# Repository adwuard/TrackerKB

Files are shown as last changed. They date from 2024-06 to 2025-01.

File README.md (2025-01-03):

### Fully Assembled units and parts are available here: 
Small batch custom build. Limited quantity now available and ready to ship!  
[Ed's Lab Shop](https://edslab.myshopify.com/)   
# Table of Contents
- [Table of Contents](#table-of-contents)
- [Overview](#overview)
- [Features](#features)
- [Hardware Guide](#hardware-guide)
    - [System Diagram](#system-diagram)
  - [Electronics Build Guide](#electronics-build-guide)
    - [Soldering](#soldering)
    - [Tips on Soldering Teensy 4.1](#tips-on-soldering-teensy-41)
  - [PCB Testing](#pcb-testing)
- [Three Versions of Enclosure are Available](#three-versions-of-enclosure-are-available)
    - [Option 1: CNC Machined Enclosure](#option-1-cnc-machined-enclosure)
    - [Option 2: Sandwiching Acrylic Enclosure](#option-2-sandwiching-acrylic-enclosure)
    - [Option 3: 3D Printed Enclosure](#option-3-3d-printed-enclosure)
- [Software Guide](#software-guide)
  - [1. Tracker Headless Firmware (Teensy 4.1)](#1-tracker-headless-firmware-teensy-41)
  - [2. Keyboard Firmware (RP2040 MCU)](#2-keyboard-firmware-rp2040-mcu)
    - [Keyboard Firmware Highlights](#keyboard-firmware-highlights)
    - [Pre-built keyboard firmware can be found here --\>  Keyboard Firmware](#pre-built-keyboard-firmware-can-be-found-here-----keyboard-firmware)
    - [Steps for Flashing Keyboard Firmware:](#steps-for-flashing-keyboard-firmware)

# Overview
This is a slightly over-engineered tracker keyboard that integrates both Teensy4.1 and a keyboard.

<div style="display: flex; flex-direction: row; margin-top: 20px;">
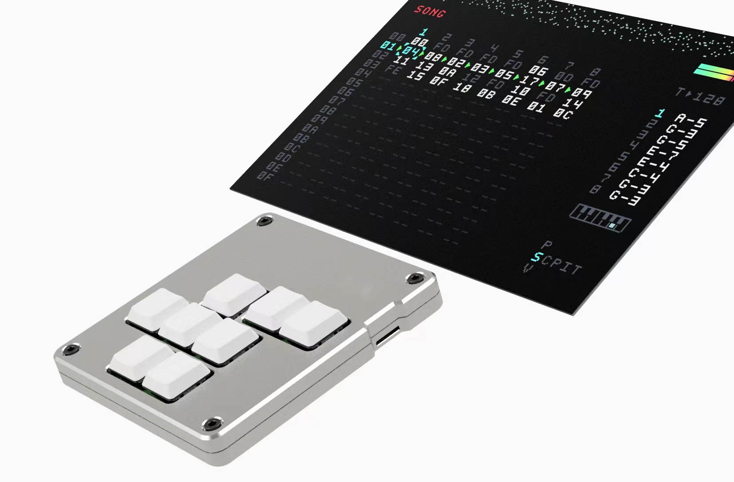
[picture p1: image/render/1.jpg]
  
</div>

<div style="display: flex; flex-direction: row; margin-top: 50px;">
  
</div>

# Features
- Built-in USB HUB connected to both Teensy 4.1 and Keyboard
- Keyboard is implemented with RP2040 microcontroller
- Same swappable mechanical keyboard as the original
- High-quality CNC machined case, providing the same handling experience as the original
- Robust connection with USB-C screw lock cable
  
# Hardware Guide
### System Diagram 
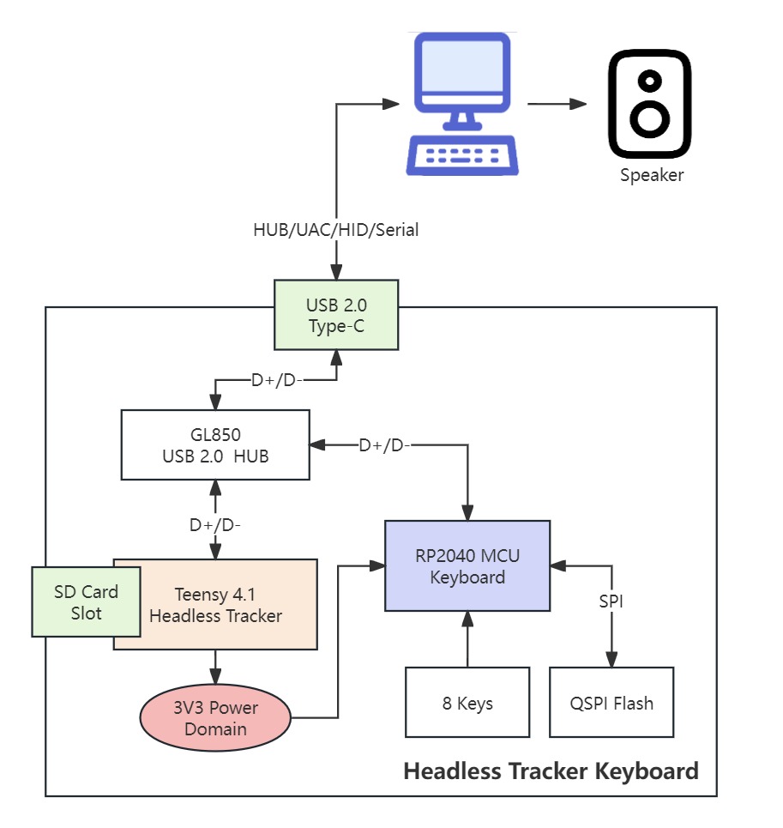
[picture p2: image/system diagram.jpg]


## Electronics Build Guide
Layer View          |  PCB (Front) |  PCB (Back)
:-------------------------:|:-------------------------:|:-------------------------:
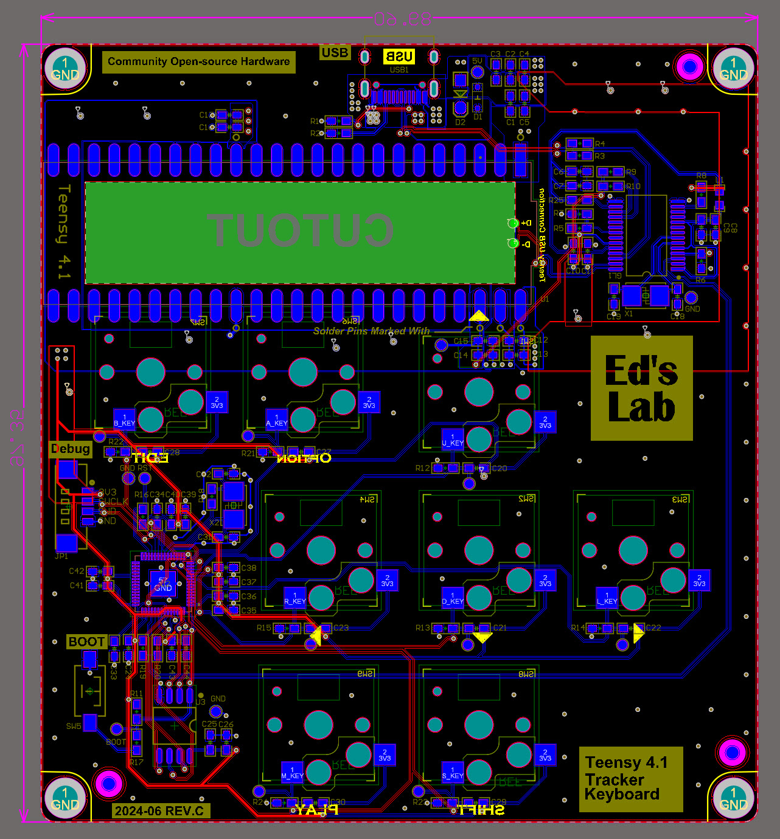
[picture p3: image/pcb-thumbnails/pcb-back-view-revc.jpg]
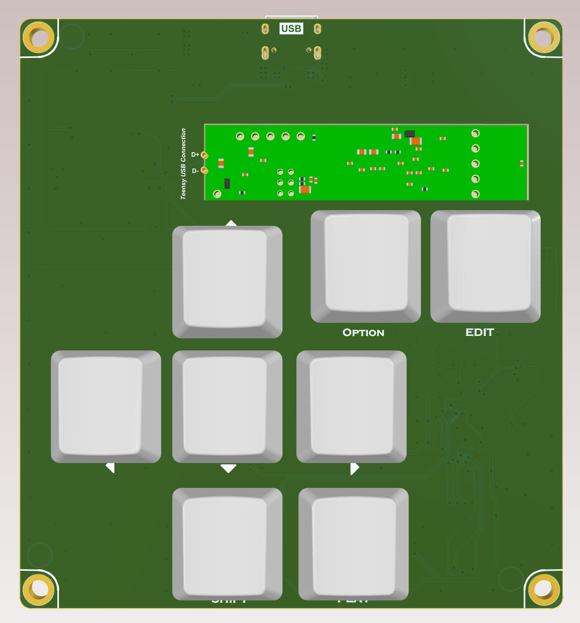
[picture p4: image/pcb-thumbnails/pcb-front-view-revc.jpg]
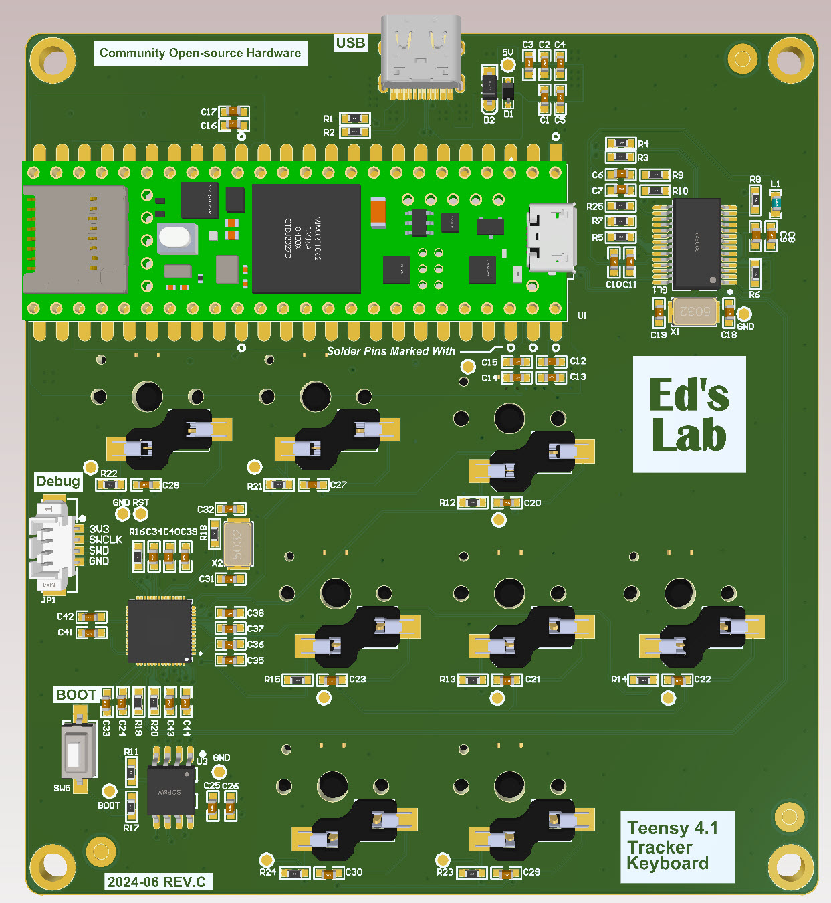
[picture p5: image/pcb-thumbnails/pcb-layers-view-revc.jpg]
 |  | 

PCB manufacture requirements: 
- Layers: `2-Layers`
- Board thickness: `1.6mm`
- Board dimensions: 90mm x 97.35mm 

All the components are 0603 footprints. The pads are designed with larger pads, making them great for hand-soldering. The most complex component in this project is the RP2040, which is in a QFN package, so hot-air reflow is required. An alternative approach is to make a custom PCB stencil, which would make the process much easier.

### Soldering
The stencil and reflow oven approach is demonstrated below and recommended. 
PCB | Stencil and Solder Paste | Pick and Place | Reflow Oven
:-:|:-:|:-:|:-:
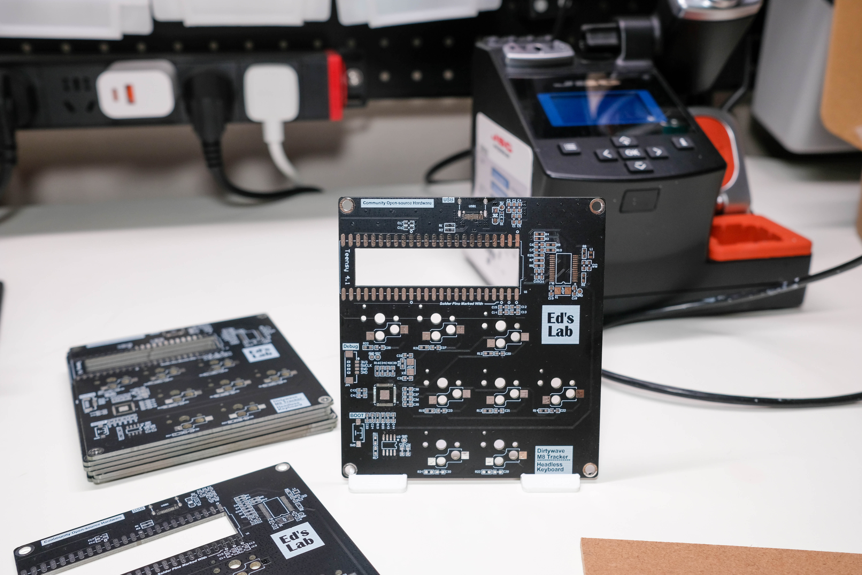
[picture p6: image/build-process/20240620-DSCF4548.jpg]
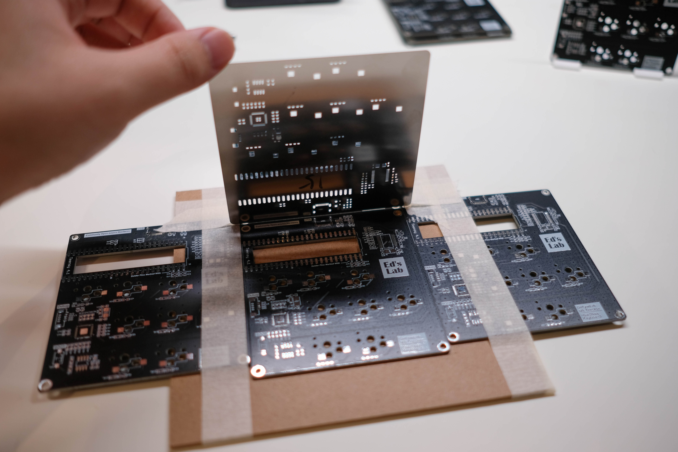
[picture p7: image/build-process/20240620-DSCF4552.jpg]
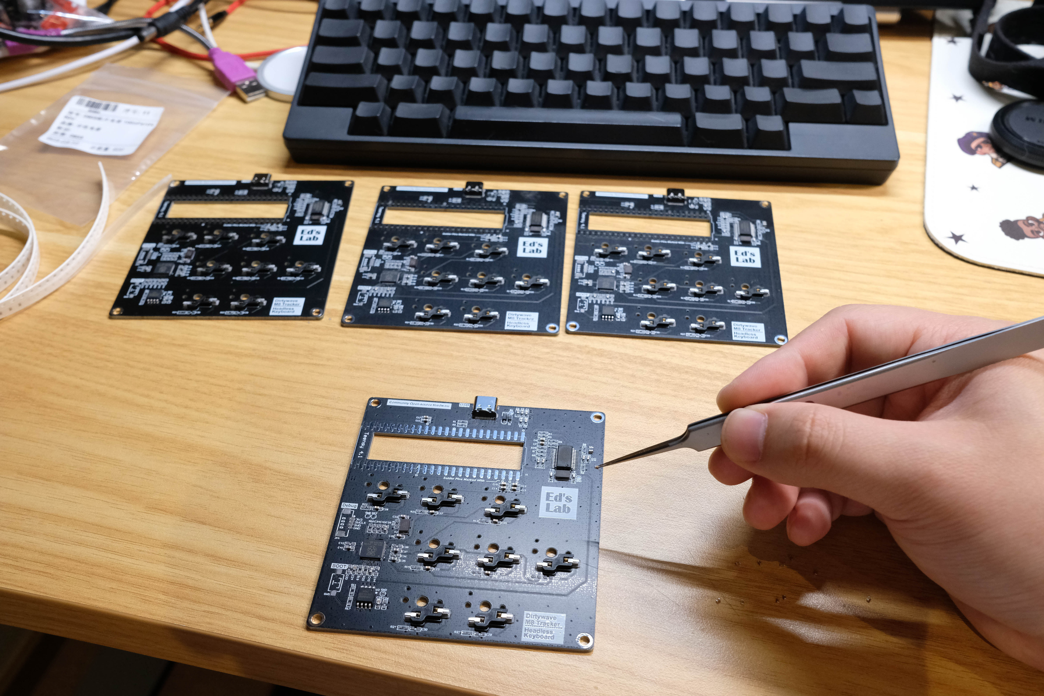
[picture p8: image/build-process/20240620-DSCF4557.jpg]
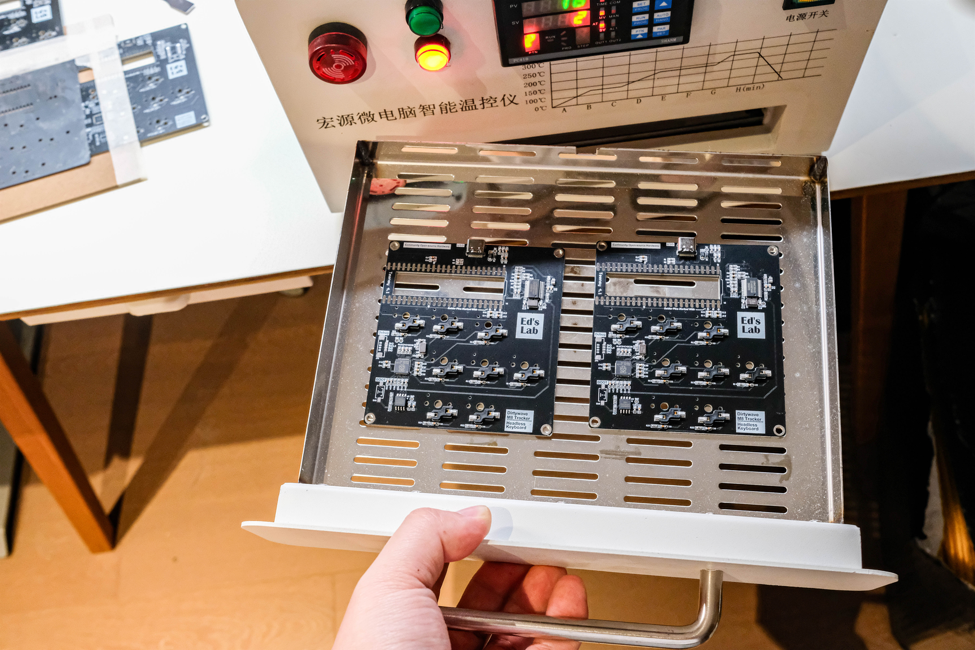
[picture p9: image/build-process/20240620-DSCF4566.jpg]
 | |  | 

### Tips on Soldering Teensy 4.1 
- Solder the pins that are marked with circles. Only 6 pins are required for soldering. This is enough to hold the board while still being easy to de-solder and repurpose if needed. To solder, add some solder flux onto the pads. Solder one pin first and ensure it's aligned properly. Place the soldering iron on the Teensy through-hole pad, and add a generous amount of solder. Hold the iron longer, around 8-15 seconds, and let the solder sink into the pad below. Then use multi-meter to test continuity between teensy pad and the pad directly below.
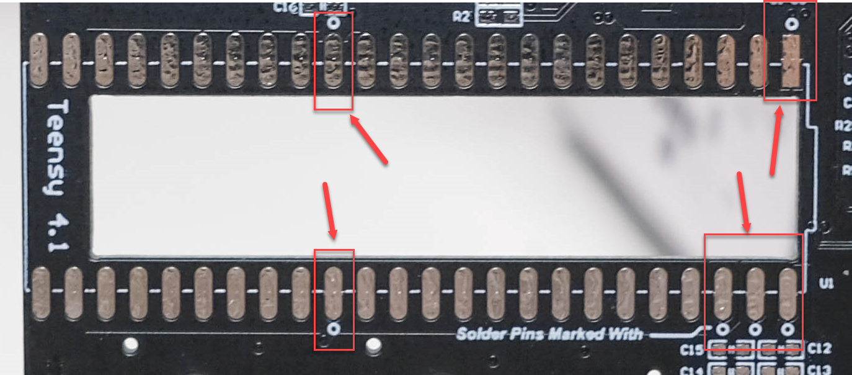
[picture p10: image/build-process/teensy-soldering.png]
  - 

REV (A/B) Hardware Teensy USB Connection
- Make a twisted wire for Teensy USB communication. Solder it and adding adhesive glue is recommended.
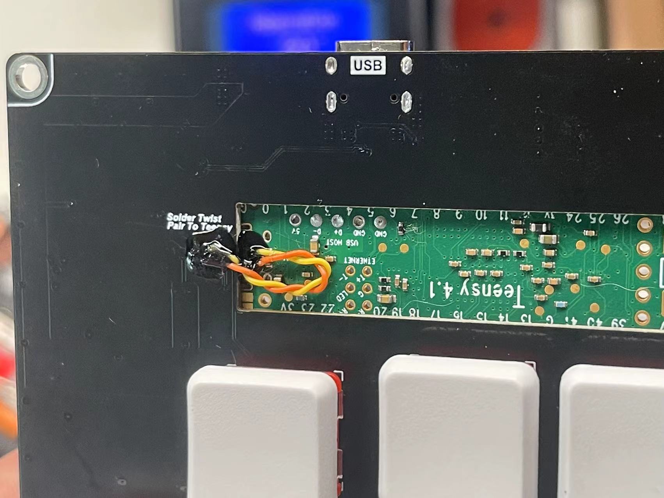
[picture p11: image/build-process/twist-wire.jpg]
  - 
REV (C) Hardware Teensy USB Connection
- In place soldering pads, solder directly with the Teensy USB Test Points
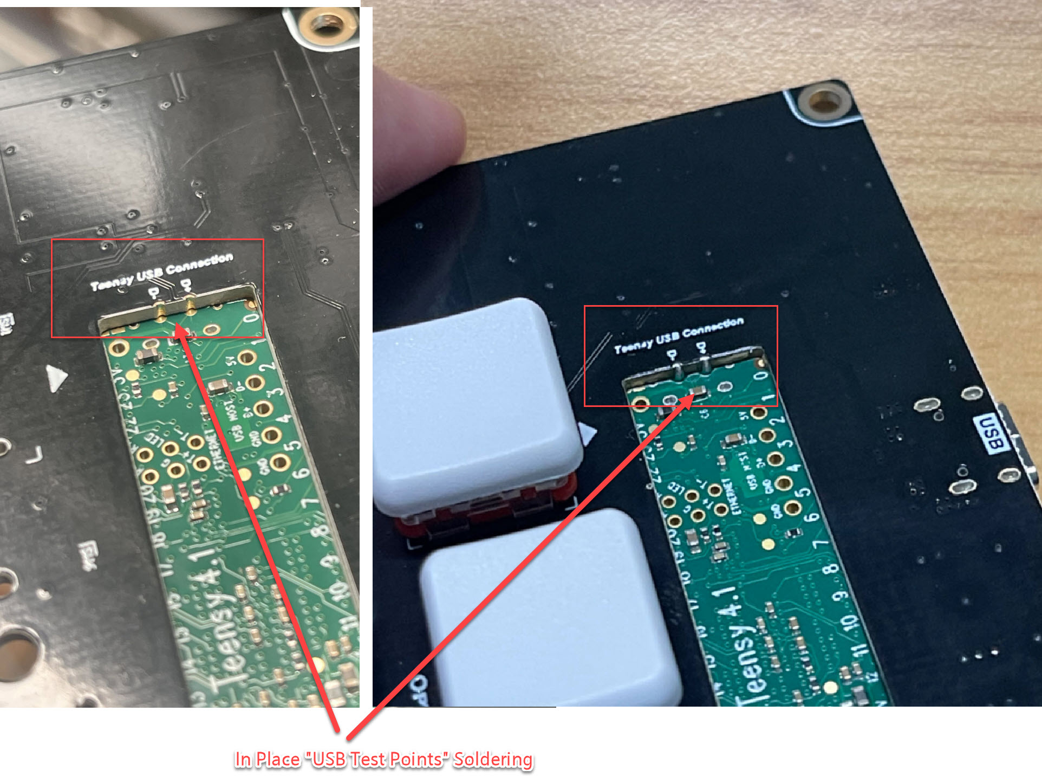
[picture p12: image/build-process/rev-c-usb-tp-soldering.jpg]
- 

## PCB Testing
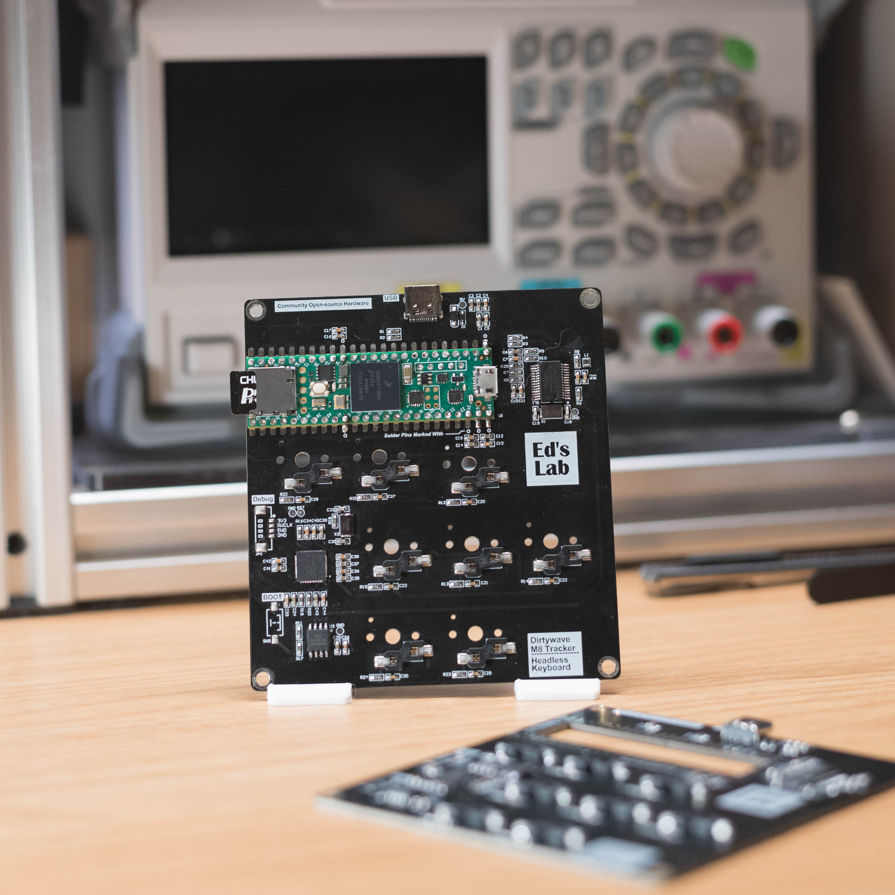
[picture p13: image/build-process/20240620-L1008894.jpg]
  

🎉🎉🎉 Great job on finishing the PCB assembly. Now we will go through a checklist and testing process to help you get your tracker keyboard up and running!

- Visually check that all components are soldered properly with no solder bridges or shorts.
- Before connecting to a PC, check that your 5V and 3V3 are not shorted to ground.
- Note that the RP2040 is powered by Teensy's on-board DC converter, so the Teensy must be soldered in order for the RP2040 to work properly.
- Follow the Software Guide section for flashing tutorials.
- You can always open the Device Manager on your PC to check if all devices are being detected properly. Three devices should show up:
  - A `USB 2.0 Hub` device
  - An Tracker `Serial` and `Audio` composite device
  - A `HID Keyboard` device

# Three Versions of Enclosure are Available
### Option 1: CNC Machined Enclosure
Best quality and experience. It's a CNC machined enclosure that offers a great hand-held experience.
```
Bill of Materials
- x4 M3x8mm screws 
- x1 CNC top and bottom case 
- x1 Optional, USB Type-C cable with screw lock (The pitch distance of the two screws is 15mm, and the size is M2 thumb screws)
- x4 8mm x 1.5mm rubber pads
- x1 12mmx12mmx1mm Thermal Pad 
```

<!-- <img src="image/cnc-build/cnc-cases.jpg" width="460"> -->

### Option 2: Sandwiching Acrylic Enclosure
A 4-layer acrylic sandwiching approach offers handling weight and durability while keeping the price cheaper compared to CNC. Note that the USB lock threads are not available in this design. The `*.dxf` files of each layer are provided for laser cut manufacturing.

How to assemble?
- Stack them up. The hole size on the layer-4 plate is slightly smaller, so screw taps will be created when screwing in the screws.
```
Bill of Materials
- x4 M3x14mm screws 
- x1 Layer 1 Acrylic (3mm thick)
- x1 Layer 2 Acrylic (3mm thick)
- x1 Layer 3 Acrylic (4mm thick)
- x1 Layer 4 Acrylic (3mm thick)
```

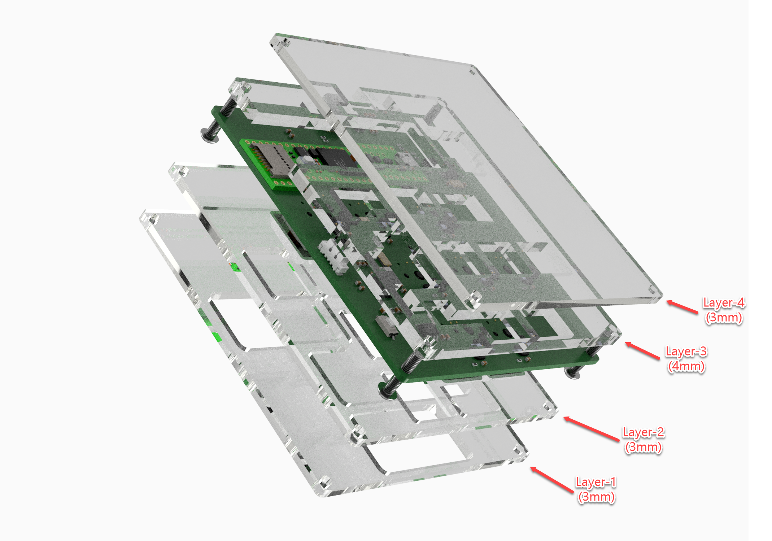
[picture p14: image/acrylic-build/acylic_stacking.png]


Assembled (Front)          |  Assembled (Back)
:-------------------------:|:-------------------------:
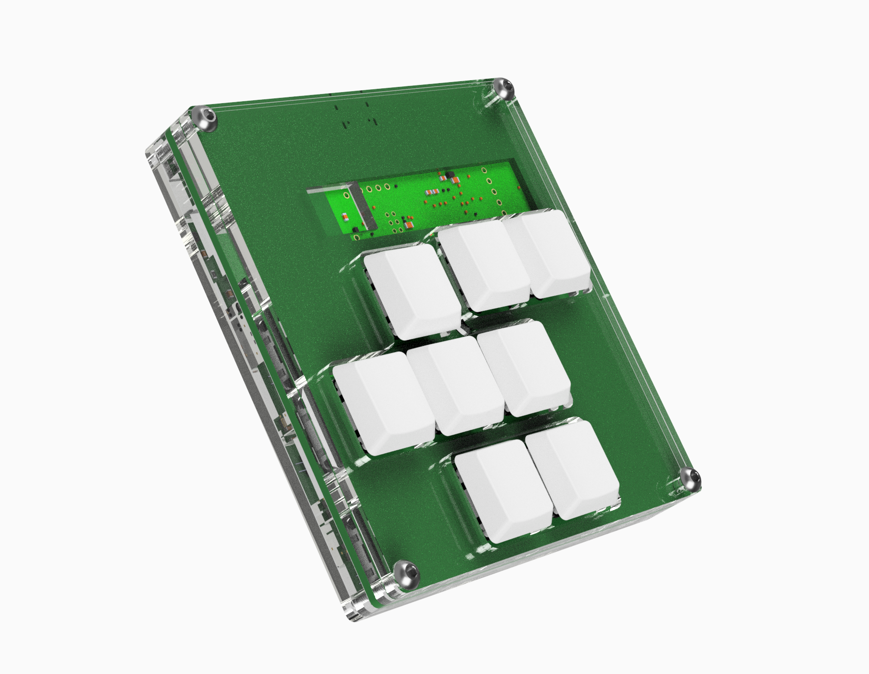
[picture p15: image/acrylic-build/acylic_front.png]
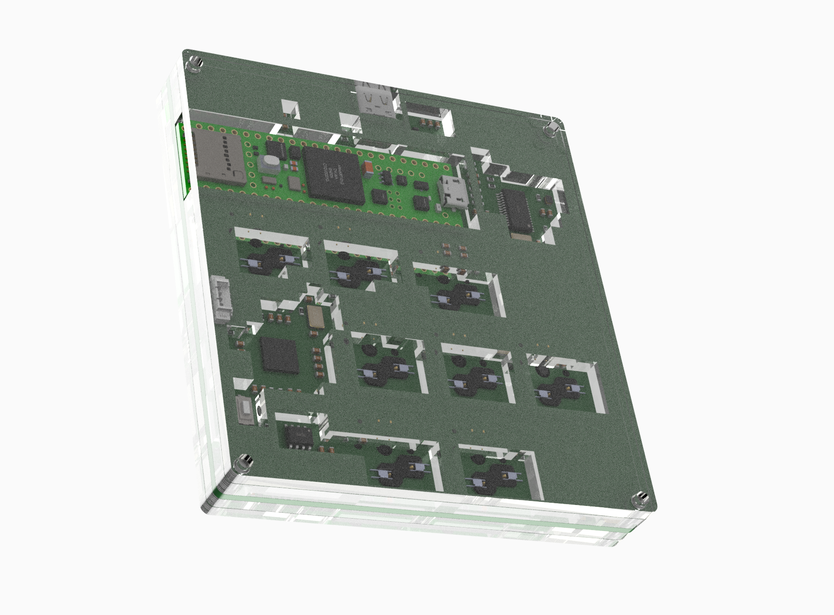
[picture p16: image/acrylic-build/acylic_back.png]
 | 

### Option 3: 3D Printed Enclosure
This 3D printed design is nearly identical to the CNC version but optimized for 3D printing. Note that the USB lock threads are not available in this design.

How to assemble?
- The hole size on the bottom case is slightly smaller, so screw taps will be created when screwing in the screws.
```
==== Print settings ==== 
- PLA or ABS filament  
- 25% infill  
- Support enabled  

==== Bill of Materials ====  
- x4 M3x8mm screws 
- x1 Printed top and bottom case
```

Slicer Build Plate         |
:-------------------------:|
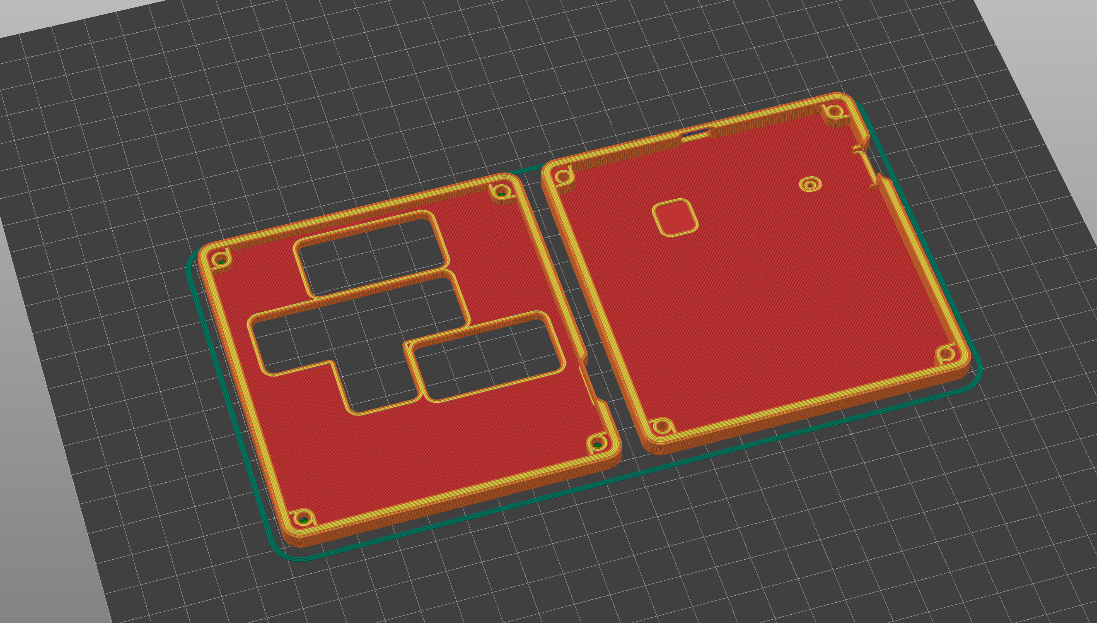
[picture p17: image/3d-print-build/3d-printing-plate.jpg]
 
<!-- <img src="image/\3d-print-build/3d-printed-demo.jpg" width="310"> -->

# Software Guide
Two firmware flashes are required:
1. Tracker Headless firmware on Teensy
2. Keyboard firmware on the RP2040 microcontroller

## 1. Tracker Headless Firmware (Teensy 4.1)
- Pre-compiled Tracker Headless Firmware and flashing guide can be found here: [Headless Firmware](https://github.com/Dirtywave/M8HeadlessFirmware)
- This is a pretty standard process and can be done easily.

## 2. Keyboard Firmware (RP2040 MCU)
The keyboard is implemented with RP2040 keyboard HID implementation. You wouldn't need to build this source file yourself. Pre-built firmware is available for easy flashing.

### Keyboard Firmware Highlights
- Implemented in C++, offering better low-latency input compared to MicroPython.
- Single firmware file. Drag and drop for a simple and fast upload process.
- No more annoying MicroPython disk pop-up every time the device is connected.
- HID key mapping: 
    (key mapping is the same as [M8 WebDisplay's](https://derkyjadex.github.io/M8WebDisplay/) default)
    | Tracker Hardware Keys | Mapped HID Keys|
    |------------------|------------------|
    |Arrow Keys| Arrow Keys|
    |Option| Z |
    |Edit| X |
    |Shift| Left Space |
    |Play| Space Bar |

### Pre-built keyboard firmware can be found here -->  [Keyboard Firmware](software/Release)
### Steps for Flashing Keyboard Firmware:
If you purchased from the Ed's Lab Shop. The default Keymap firmware works with `M8 Web Display` Client. If you want `M8C` as your default client. 
Please follow the following guide:  


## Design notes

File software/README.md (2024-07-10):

# Tracker M8 Keyboard Software

# Overview
This is source code for RP2040 keyboard HID implementation. You wouldn't need to build this source file yourself. Pre-built firmware is available for easy flashing.

# Steps for flashing M8 tracker keyboard firmware:
## For Most Users:
- Download single firmware `pico-m8-keyboard.uf2` file from the `Release` Folder
- "Press and Hold" the `Boot` button on the RP2040 board, and connect the usb to your PC, then release `Boot` button.
- A disk will showup or mounted. It means you RP2040 is in boot-loader mode and ready to load firmware.
- Simply drag and drop the `pico-m8-keyboard.urf` firmware file to the mounted disk.
- RP2040 will then unmount and reboot itself to new firmware

That simple!

## Developer:
- Follow quick start guide from Raspberry PI RP2040 documentation. 
- Install Pico SDK base on your system environment.
  
```shell
git submodule update

# make sure PICO_SDK is installed and sourced in your environment
cd src && mkdir ./build && cd build
cmake ..
ninja # builds elf/bin/uf2 firmware into same folder
```

## Q&A
### How is it different than MicroPython version?
- This is implemented in C++. Compare to MicroPython's interrupt language This offers even lower input latency!
- One firmware file only, simple upload
- No more annoying disk pop-up everytime  when the device is connected

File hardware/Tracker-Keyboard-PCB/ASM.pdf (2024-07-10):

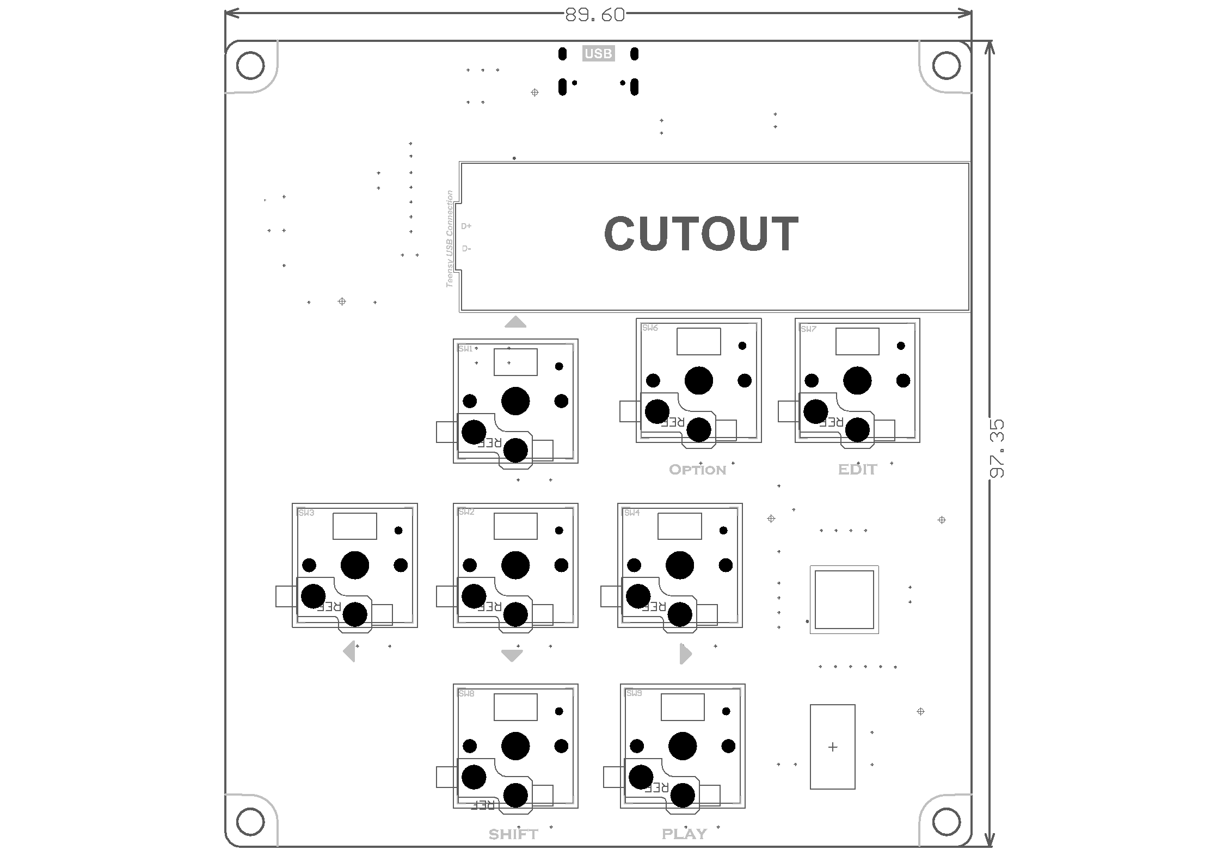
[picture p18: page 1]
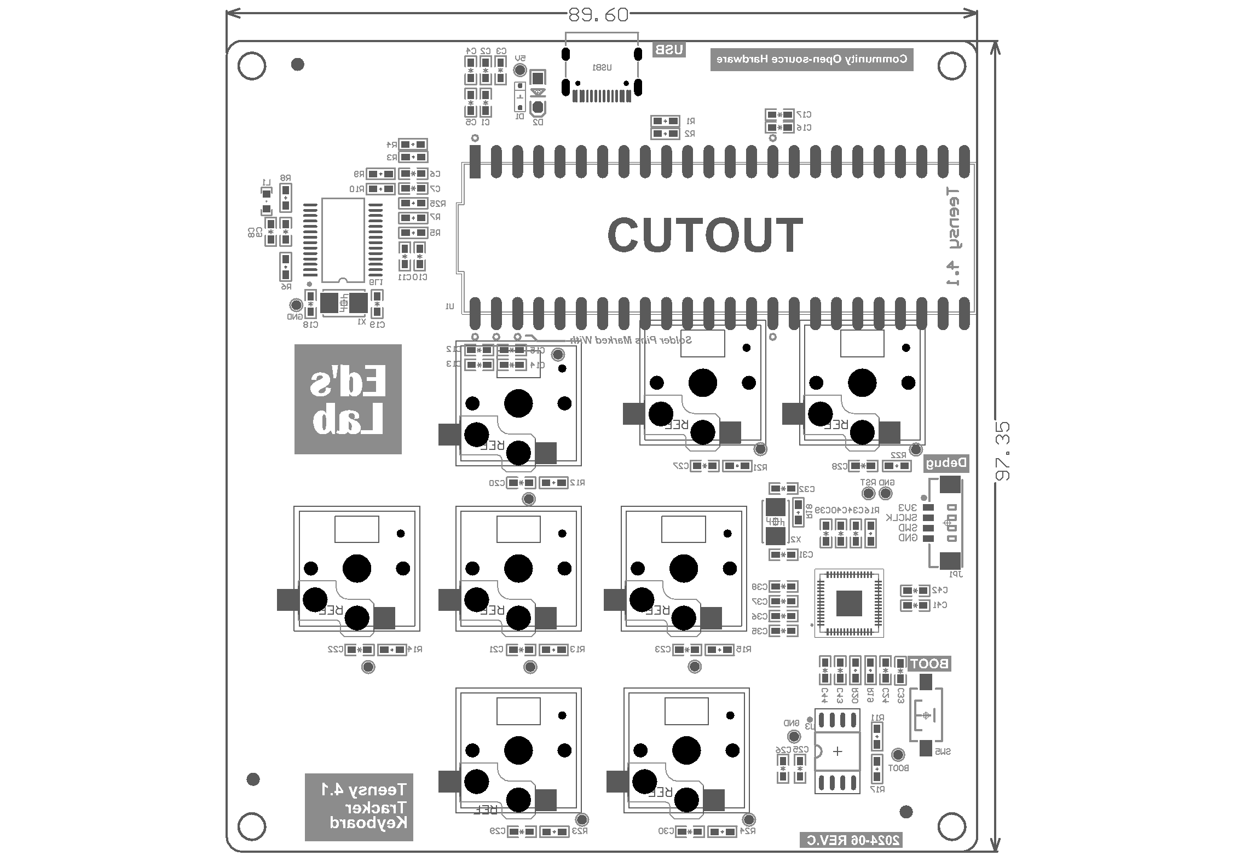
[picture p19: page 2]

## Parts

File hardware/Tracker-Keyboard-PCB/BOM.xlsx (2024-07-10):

Comment | Description | Designator | Footprint | Quantity
10uF | Capacitor, 0603 Capacitor | C1, C2, C3, C6, C10, C12, C14, C16, C25, C35, C37, C39, C41, C43 | C0603_M | 14 | open/any
100nF | Capacitor, 0603 Capacitor | C4, C5, C7, C8, C9, C11, C13, C15, C17, C20, C21, C22, C23, C26, C27, C28, C29, C30, C33, C34, C36, C38, C40, C42, C44 | C0603_M | 25 | open/any
33p | Capacitor | C18, C19 | C0603_M | 2 | open/any
1uF | 0603 Capacitor | C24 | C0603_M | 1 | open/any
15p | Capacitor | C31, C32 | C0603_M | 2 | open/any
1N5819 | 1N5819 | D1 | SOD-323 | 1 | open/any
ESD ZESD5V0D1 SOD-123 | ESD Protection ZN-SOD123 DL21 5V6 | D2 | SOD-123 | 1 | open/any
GL850G | Programmable Logic IC Development Tools | GL1 | SSOP28 | 1
BEADS | BEADS 30R 0603 | L1 | L0603 | 1 | open/any
5.1K | Resistor, 0603 1% Resistor, 0603 Resistor | R1, R2, R5, R16 | R0603_M | 4 | open/any
22R | Resistor, 0603 Resistor | R3, R4, R25 | R0603_M | 3 | open/any
680 | 0603 1% Resistor | R6 | R0603_M | 1 | open/any
10K | 0603 Resistor | R7, R8, R10, R11, R12, R13, R14, R15, R21, R22, R23, R24 | R0603_M | 12 | open/any
100K | 0603 Resistor | R9 | R0603_M | 1 | open/any
1K | 0603 1% Resistor, 0603 Resistor | R17, R18 | R0603_M | 2 | open/any
27.4 | 0603 Resistor | R19, R20 | R0603_M | 2 | open/any
Kailh 5118-Choc-Socket | Kailh 5118-Choc-Socket | SW1, SW2, SW3, SW4, SW6, SW7, SW8, SW9 | Kailh_socket_PG1350 | 8
Teensy 4_1 | Teensy 4_1 MCU | U1 | TEENSY4_1_SMT_SOP48 | 1 | Hand Soldered
RP2040 | RP2040 chip for Raspberry Pi Pico - ARM® Cortex®-M0+ MCU 32-Bit | U2 | QFN40P700X700X90-57N | 1
W25Q16JVSIQ | FLASH - NOR Memory IC 16Mb (2M x 8) SPI - Quad I/O, QPI, DTR 133 MHz 8-SOIC | U3 | SOIC-8W | 1
Type-C | 16P USB Type-C Connector | USB1 | Type-C-TOP | 1
12MHz | 2P Crystal 12MHZ | X1, X2 | XTAL-5032-2P | 2

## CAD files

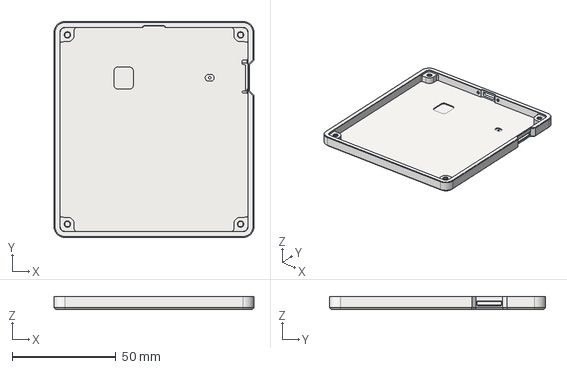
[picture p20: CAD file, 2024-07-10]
hardware/Enclosure/1_CNC-Case/Bottom_Case.step
96.6 x 104.3 x 6.44 mm

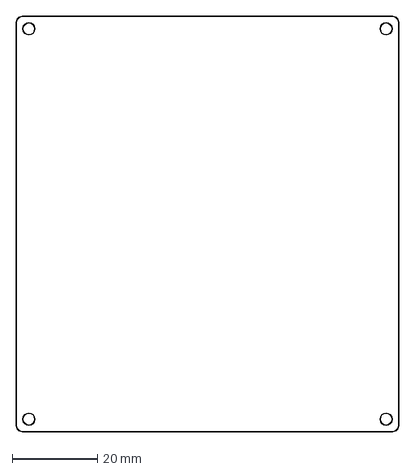
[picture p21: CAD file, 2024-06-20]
hardware/Enclosure/2_Acylic-Case/layer-4-export-3mm.dxf
89.6 x 97.3 mm

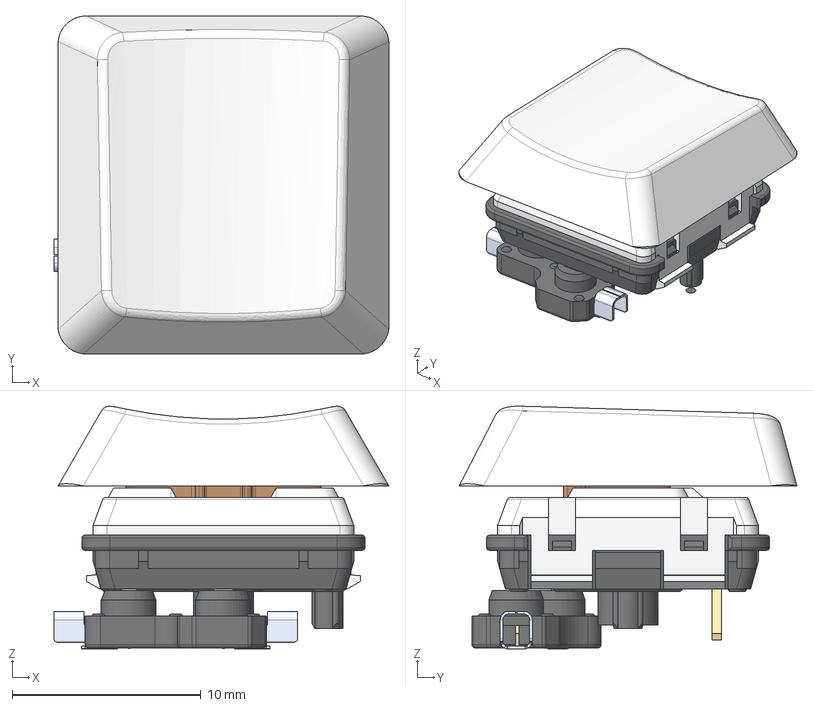
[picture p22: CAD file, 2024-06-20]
hardware/Tracker-Keyboard-PCB/datasheets_and_footprints/Kailh/Key_ASEM v3.step
17.7 x 17.9 x 12.9 mm
pin x 2
socket
Kailh LP Choc PC Keycap

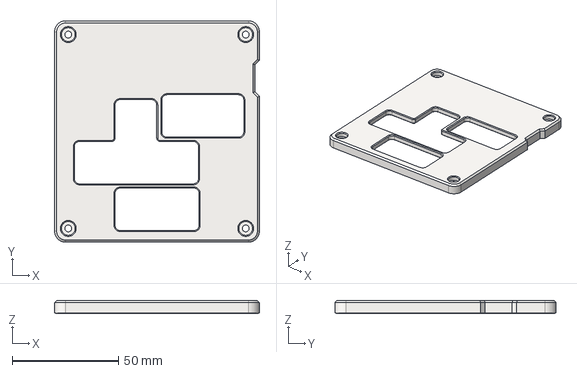
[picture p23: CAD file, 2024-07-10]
hardware/Enclosure/1_CNC-Case/Top_Case.step
96.6 x 104.3 x 6.20 mm

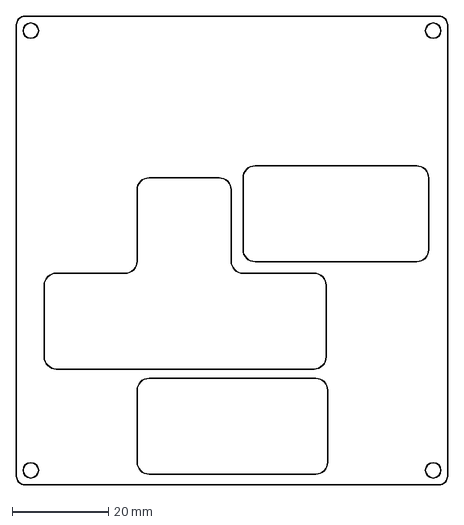
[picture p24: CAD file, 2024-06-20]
hardware/Enclosure/2_Acylic-Case/layer-1-export-3mm.dxf
89.6 x 97.3 mm

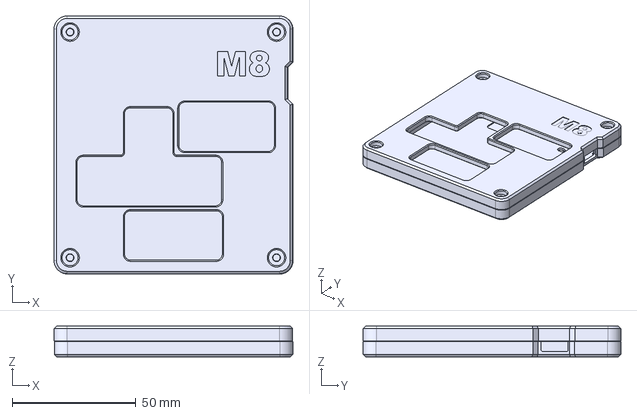
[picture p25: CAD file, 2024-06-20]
hardware/Enclosure/3_3D-Printed-Case/3d-case-top.step
96.8 x 104.4 x 12.5 mm
Bottom_Case (1)
Top_Case (1)

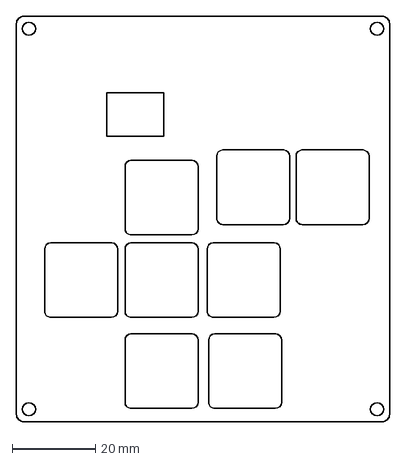
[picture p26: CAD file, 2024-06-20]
hardware/Enclosure/2_Acylic-Case/layer-2-export-3mm.dxf
89.6 x 97.3 mm

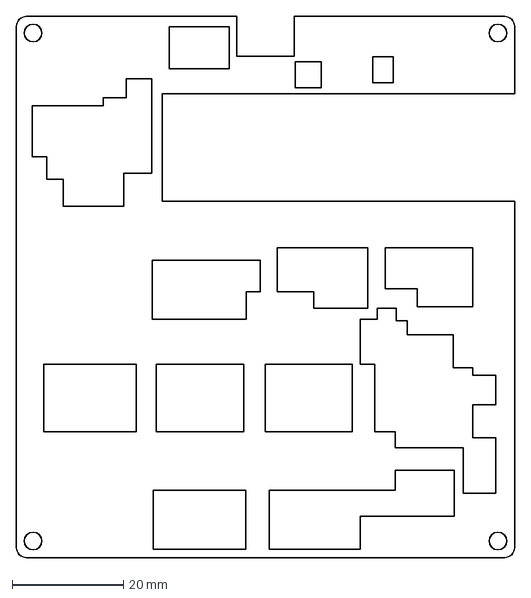
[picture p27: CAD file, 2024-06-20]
hardware/Enclosure/2_Acylic-Case/layer-3-export-4mm.dxf
89.6 x 97.3 mm

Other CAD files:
hardware/Enclosure/3_3D-Printed-Case/3d-case-bottom.step

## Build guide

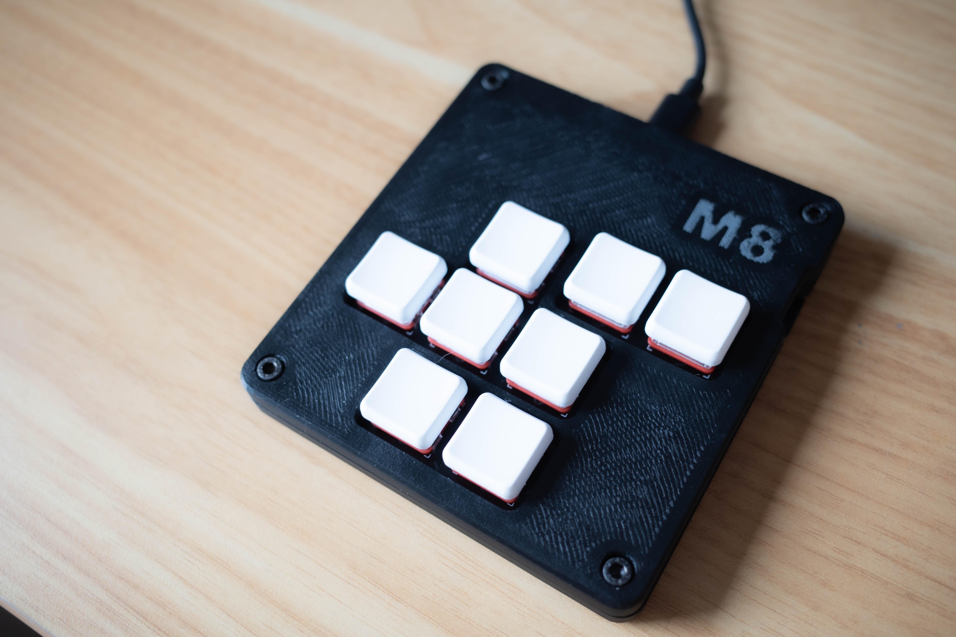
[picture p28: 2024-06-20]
image/3d-print-build/3d-printed-demo.jpg

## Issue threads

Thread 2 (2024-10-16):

CNC hardware source missing drill file

Synthesizer-repair, 2024-10-16:
Noticed that the CNC does not include the drill file.  It would be great to have that file included in the hardware sources, so that the holes needed can be drilled and properly tapped with threads using MFG services.

adwuard, 2024-10-18:
Thanks for the input!
I am not quite familiar with the CAM drill file, and how it can be generated with Fusion360. Usually, I would just need to point out where to tap and my local CNC services does it.

In terms of drill file maybe a little more info and direction on what kind of files is needed. I might be able to figure it out on how to generate with Fusion 360.
Or, I could generate 2D PDFs indicate drill and thread size.

DOSputin, 2024-10-18:
If we're going to the trouble of a PCB & enclosure redesign, why not also include analog audio I/O on 3.5mm also?
Using a shield PCB with all these I/O, midi & audio, works with headless m8.  ie: https://codeberg.org/dcoredump/TeensyMIDIAudio/src/branch/master/T4.1-Adapter-Board_Rev-1.0

Seems like it would be worth the efforts?

adwuard, 2024-10-22:
@Synthesizer-repair I see, CAM and G-code I do familiar. But G-code and tool paths this usually generated by the CNC fab house. Since the tools, and machines are different. Some more qualified CNC fab house even have auto tool change for tapping. Some do it at post manually. For automated tool change or tapping This requires custom G-code commands and database of their tool-sets. And not all fab house have same tooling and capabilities. It's impossible to generate on G-Code/Drill file to fit all.
What I can do with my local CNC shop is to provide 3D STEP and 2D CAD notes for the parts. And fab house decides how to do their tool paths and how they want to tap the holes.

adwuard, 2024-10-22:
@DOSputin I've heard that Dirtywave removed their MIDI support with their M8 headless firmware. I'm not sure if the MIDI would still work.

DOSputin, 2024-10-22:
> @DOSputin I've heard that Dirtywave removed their MIDI support with their M8 headless firmware. I'm not sure if the MIDI would still work.

Umm, you heard?
It works.  There is nothing preventing, you simply have to connect the proper hardware.
Install headless firmware on an official M8 massively overpriced hardware, the MIDI I/O works.  It's on pins 1 & 28...

adwuard, 2024-10-23:
@DOSputin  Here more information on the MIDI being removed in headless version that greater than V2.0.

Source: Youtube
https://www.youtube.com/watch?v=BEqFc5MtHGY
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

Source: Discord User Group
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

Closed 2024-10-23.

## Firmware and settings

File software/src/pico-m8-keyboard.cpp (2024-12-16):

/*
 * The MIT License (MIT)
 *
 * Copyright (c) 2024 Hsuan Han Lai
 *
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
 *
 * Changes Made:
    ## 06-18-2024
    - HID keyboard implementation
    - Added multi-keys support and key defintion for M8 Tracker Headless
 */

#include "pico/stdlib.h"
#include "hardware/gpio.h"
#include "pico/binary_info.h"

#include "includes/usb.h"
#include "includes/Adafruit_USBD_CDC-stub.h"
#include "Adafruit_TinyUSB_Arduino/src/Adafruit_TinyUSB.h"
#include "TinyUSB_Mouse_and_Keyboard/TinyUSB_Mouse_and_Keyboard.h"

// GPIO pins of the key switch
#define KEY_UP_PIN 9
#define KEY_DOWN_PIN 10
#define KEY_LEFT_PIN 7
#define KEY_RIGHT_PIN 8
#define KEY_OPTION_PIN 11
#define KEY_EDIT_PIN 12
#define KEY_SHIFT_PIN 13
#define KEY_PLAY_PIN 14

// Adafruit TinyUSB instance
extern Adafruit_USBD_Device TinyUSBDevice;

// Key code mapping for the keys
static const int kMaxKeys = 8;

#ifdef USE_M8C
static const char keys_map[kMaxKeys][2] = {
    {KEY_UP_PIN, KEY_UP_ARROW}, // mapped to arrow up
    {KEY_DOWN_PIN, KEY_DOWN_ARROW}, // mapped to arrow down
    {KEY_LEFT_PIN, KEY_LEFT_ARROW}, // mapped to arrow left
    {KEY_RIGHT_PIN, KEY_RIGHT_ARROW}, // mapped to arrow right
    {KEY_OPTION_PIN, 'a'}, // mapped to 'a' key
    {KEY_EDIT_PIN, 's'}, // mapped to 's' key
    {KEY_SHIFT_PIN, KEY_LEFT_SHIFT}, // mapped to Left shift
    {KEY_PLAY_PIN, ' '}  // mapped to Space-bar
};
#elif defined(USE_M8_WEB_DISPLAY)
static const char keys_map[kMaxKeys][2] = {
    {KEY_UP_PIN, KEY_UP_ARROW}, // mapped to arrow up
    {KEY_DOWN_PIN, KEY_DOWN_ARROW}, // mapped to arrow down
    {KEY_LEFT_PIN, KEY_LEFT_ARROW}, // mapped to arrow left
    {KEY_RIGHT_PIN, KEY_RIGHT_ARROW}, // mapped to arrow right 
    {KEY_OPTION_PIN, 'z'}, // mapped to 'z' key
    {KEY_EDIT_PIN, 'x'}, // mapped to 'x' key
    {KEY_SHIFT_PIN, KEY_LEFT_SHIFT}, // mapped to Left shift
    {KEY_PLAY_PIN, ' '}  // mapped to Space-bar
};
#endif

static const int kDebounceDelay = 5;
static uint32_t debounce[kMaxKeys][2];

int main() {
    bi_decl(bi_program_description("Tracker Keyboard"));
    bi_decl(bi_program_feature("USB HID Device"));

    board_init();
    TinyUSBDevice.begin();
    Keyboard.begin();

    for (int i = 0; i < kMaxKeys; i++) {
        gpio_init(keys_map[i][0]);
        gpio_set_dir(keys_map[i][0], GPIO_IN);
        gpio_pull_down(keys_map[i][0]);
        debounce[i][0] = 0;
        debounce[i][1] = to_ms_since_boot(get_absolute_time());
    }

    while (1) {
        for (int i = 0; i < kMaxKeys; i++) {
            bool state = gpio_get(keys_map[i][0]);
            uint32_t now = to_ms_since_boot(get_absolute_time());
            if ((now - debounce[i][1] > kDebounceDelay) && state != debounce[i][0]) {
                if (!state)
                    Keyboard.release(keys_map[i][1]);
                else
                    Keyboard.press(keys_map[i][1]);
                debounce[i][0] = state;
                debounce[i][1] = now;
            }
        }
    }
}

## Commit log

2024-06-18 pico HID tracker keyboard implementation init commit
2024-06-20 PCB source file init commit, REV_B
    [28SSOP.PcbLib, AP2112K-3.3TRG1.SchLib, DEV-16771.SchLib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]
2024-06-20 add hardware enclosure design and fab
    [3d-case-bottom.step, 3d-case-top.step, cnc-case-bottom.step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]
2024-06-20 add BOM
    [M8-Keyboard_PCB-BOM.xlsx]
2024-06-21 add cnc case build images
2024-06-25 update dir and naming
    [28SSOP.PcbLib, AP2112K-3.3TRG1.SchLib, DEV-16771.SchLib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]
2024-07-10 update: pcb FAB to REV-C
    [BOM.xlsx, M8-Keyboard_PCB.PrjPcb, Sheet1.SchDoc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]
2024-07-10 add pcb release notes
2024-07-10 update casing 3D, remove M8 markings
    [Bottom_Case.step, Top_Case.step, cnc-case-bottom.step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]
2024-08-06 add rev.c tp soldering img
